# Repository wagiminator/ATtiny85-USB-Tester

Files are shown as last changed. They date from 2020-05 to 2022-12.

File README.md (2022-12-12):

# USB Power Tester
Simple USB Power Tester based on ATtiny25/45/85 and INA219. The device measures voltage, current, power, energy, capacity and displays the values on an OLED screen. You can switch between different screens by pressing the SET button.

- Project Video (YouTube): https://youtu.be/QKx8Vn_IfjU
- Design Files (EasyEDA): https://easyeda.com/wagiminator/attiny85-usb-tester

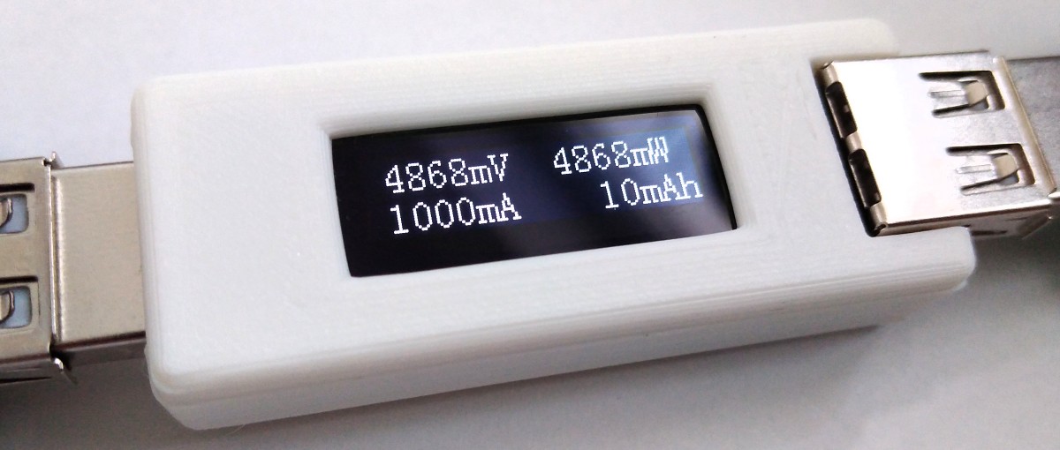
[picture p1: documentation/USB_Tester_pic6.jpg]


# Hardware
## USB Connectors
The device is equipped with a USB-A plug for the input and a USB-A socket for the output, so that it can be plugged between the power supply and the consumer. D+ and D- are passed through so that the consumer can negotiate the charging protocol.

## Voltage and Current Measurement
An [INA219](https://www.ti.com/lit/ds/symlink/ina219.pdf) is used to measure voltage and current. The INA219 is a current shunt and power monitor with an I²C-compatible interface. The device monitors both shunt voltage drop and bus supply voltage, with programmable conversion times and filtering. A programmable calibration value, combined with an internal multiplier, enables direct readouts of current in amperes. The selected shunt resistance of 8mΩ enables both a very small influence on the circuit and a measurement with a resolution of 1mA. For an accurate measurement, a shunt resistor with a low tolerance (1% or better) should be selected.

## User Interface
The user interface utilizes two buttons and an [SSD1306 128x32 pixels OLED display](http://aliexpress.com/wholesale?SearchText=128+32+0.91+oled). An [ATtiny24/45/85](https://ww1.microchip.com/downloads/en/DeviceDoc/Atmel-2586-AVR-8-bit-Microcontroller-ATtiny25-ATtiny45-ATtiny85_Datasheet.pdf) microcontroller handles the user interface as well as the calculation and  display of the values.

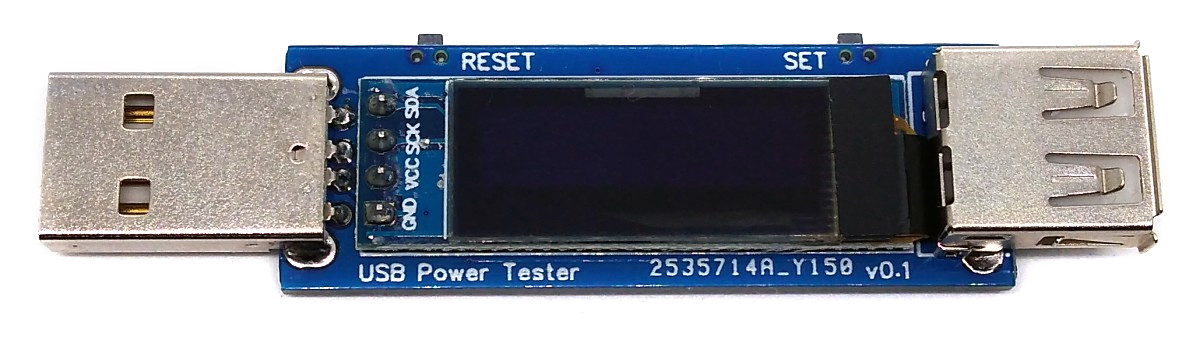
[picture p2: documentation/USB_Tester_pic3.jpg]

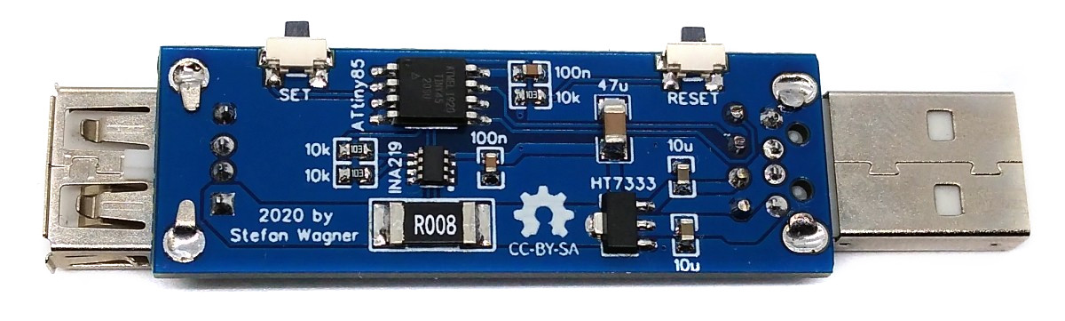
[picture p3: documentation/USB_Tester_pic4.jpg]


# Software
## Basic Principle
The INA219 continuously measures current and voltage and transmits the values to the ATtiny via I²C. From this, the ATtiny calculates the other values and displays them on the OLED screen.

## I²C OLED Implementation
The I²C protocol implementation is based on a crude bitbanging method. It was specifically designed for the limited resources of ATtiny10 and ATtiny13, but it works with some other AVRs (including the ATtiny25/45/85) as well. The functions for the OLED are adapted to the SSD1306 OLED module, but they can easily be modified to be used for other modules. In order to save resources, only the basic functionalities which are needed for this application are implemented. For a detailed information on the working principle of the I²C OLED implementation visit [TinyOLEDdemo](https://github.com/wagiminator/attiny13-tinyoleddemo).

## Accuracy of Time and Capacity Determination
The internal oscillator of the ATtiny is used to determine energy and capacity. The accuracy of the internal oscillator is +/-10% with the factory calibration. This can be improved to +/-2% or better by [manual calibration](https://github.com/wagiminator/ATtiny84-TinyCalibrator). The calibration value determined in this way can be set in the source code.

## Compiling and Uploading
Since there is no ICSP header on the board, you have to program the ATtiny either before soldering using an [SOP adapter](https://aliexpress.com/wholesale?SearchText=sop-8+150mil+adapter), or after soldering using an [EEPROM clip](https://aliexpress.com/wholesale?SearchText=sop8+eeprom+programming+clip). The [AVR Programmer Adapter](https://github.com/wagiminator/AVR-Programmer/tree/master/AVR_Programmer_Adapter) can help with this.

### If using the Arduino IDE
- Make sure you have installed [ATtinyCore](https://github.com/SpenceKonde/ATTinyCore).
- Go to **Tools -> Board -> ATtinyCore** and select **ATtiny25/45/85 (No bootloader)**.
- Go to **Tools** and choose the following board options:
  - **Chip:**           ATtiny25 or 45 or 85 (depending on your chip)
  - **Clock:**          1 MHz (internal)
  - **B.O.D.Level:**    B.O.D. enabled (2.7V)
  - Leave the rest at the default settings
- Connect your programmer to your PC and to the ATtiny.
- Go to **Tools -> Programmer** and select your ISP programmer (e.g. [USBasp](https://aliexpress.com/wholesale?SearchText=usbasp)).
- Go to **Tools -> Burn Bootloader** to burn the fuses.
- Open USB_Tester sketch and click **Upload**.

### If using the precompiled hex-file
- Make sure you have installed [avrdude](https://learn.adafruit.com/usbtinyisp/avrdude).
- Connect your programmer to your PC and to the ATtiny.
- Open a terminal.
- Navigate to the folder with the hex-file.
- Execute the following command (if necessary replace "usbasp" with the programmer you use):
  ```
  avrdude -c usbasp -p t85 -U lfuse:w:0x62:m -U hfuse:w:0xd5:m -U efuse:w:0xff:m -U flash:w:usb_tester.hex
  ```

### If using the makefile (Linux/Mac)
- Make sure you have installed [avr-gcc toolchain and avrdude](http://maxembedded.com/2015/06/setting-up-avr-gcc-toolchain-on-linux-and-mac-os-x/).
- Connect your programmer to your PC and to the ATtiny.
- Open a terminal.
- Navigate to the folder with the makefile and the Arduino sketch.
- Run `DEVICE=attiny85 PROGRMR=usbasp make install` to compile, burn the fuses and upload the firmware (change DEVICE and PROGRMR accordingly).

# Operating Instructions
1. Connect the device between a power supply and a consumer.
2. Use the SET button to switch between the different screens.
3. Use the RESET button to reset all values.

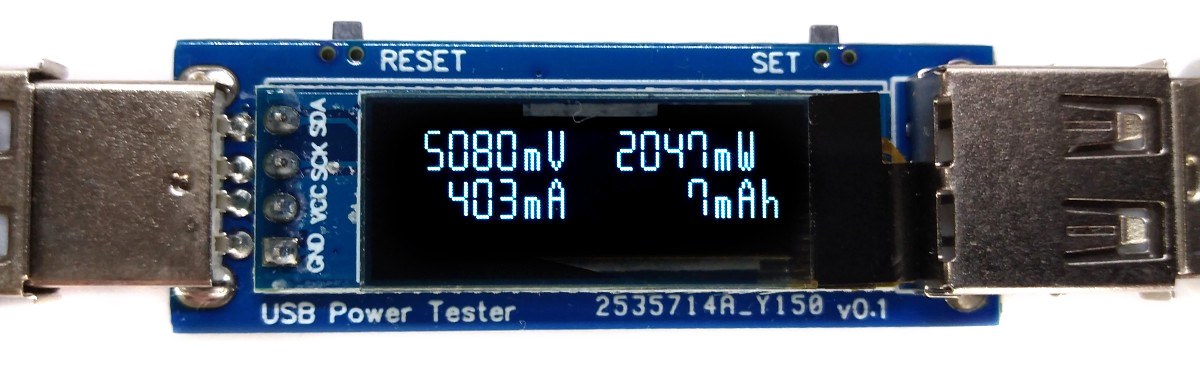
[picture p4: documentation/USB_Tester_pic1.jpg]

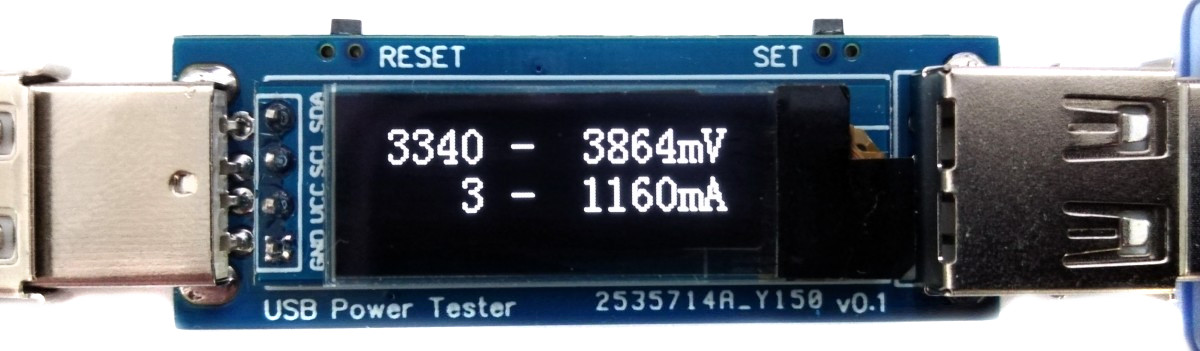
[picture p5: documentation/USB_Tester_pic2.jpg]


# Characteristics
|Parameter|Value|
|-|-|
|Voltage|3V - 12V|
|Current|max 5A|
|Voltage Measurement Resolution|4mV|
|Current Measurement Resolution|1mA|

# References, Links and Notes
1. [UBS Type-C Version](https://github.com/wagiminator/ATtiny85-USB-C-Tester)
2. [ATtiny25/45/85 Datasheet](https://ww1.microchip.com/downloads/en/DeviceDoc/Atmel-2586-AVR-8-bit-Microcontroller-ATtiny25-ATtiny45-ATtiny85_Datasheet.pdf)
3. [INA219 Datasheet](https://www.ti.com/lit/ds/symlink/ina219.pdf)
4. [SSD1306 Datasheet](https://cdn-shop.adafruit.com/datasheets/SSD1306.pdf)
5. [128x32 OLED on Aliexpress](http://aliexpress.com/wholesale?SearchText=128+32+0.91+oled)

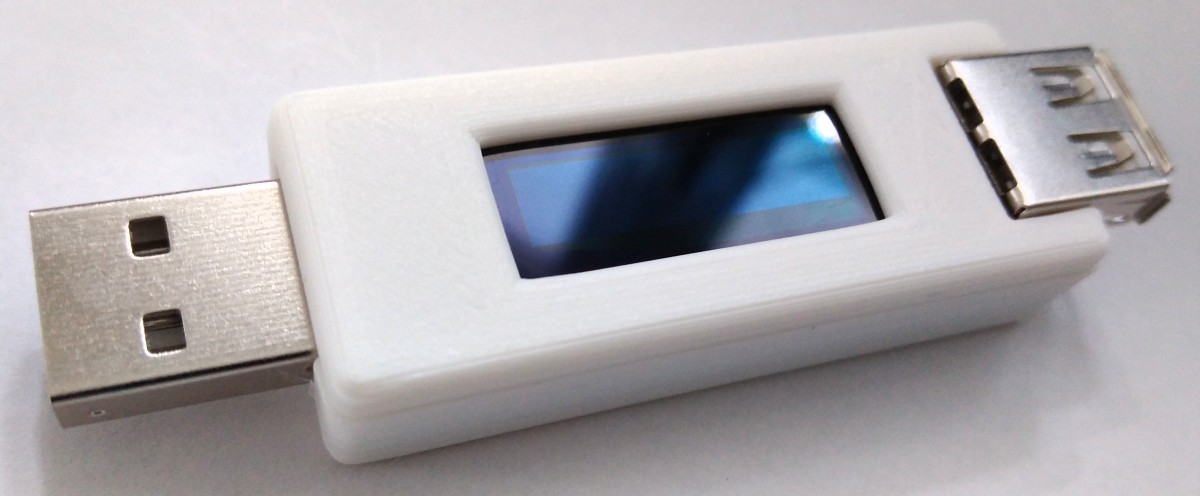
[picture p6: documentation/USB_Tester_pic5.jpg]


# License


This work is licensed under Creative Commons Attribution-ShareAlike 3.0 Unported License. 
(http://creativecommons.org/licenses/by-sa/3.0/)

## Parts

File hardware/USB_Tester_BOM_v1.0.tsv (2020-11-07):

ID | Name | Designator | Footprint | Quantity | Manufacturer Part | Manufacturer | Supplier | Supplier Part | LCSC Assembly
1 | OLED 0.91 | OLED | I2C OLED 0.91 | 1 | SSD1306 I2C OLED
2 | POWER OUT | USB2 | USB-2.0-A-F-90-JCJ-H9.36 | 1 | USB-A-F-90 | LCSC | LCSC | C168708
3 | POWER IN | USB1 | USB-M-48 | 1 | USB-05 | SOFNG | LCSC | C112454
4 | TS24CA | RESET,SET | SW-SMD_TS24CA | 2 | TS24CA | SHOU HAN | LCSC | C393942
5 | 10k | R3,R4,R1 | 0603 | 3 | 0603WAF1002T5E | UniOhm | LCSC | C25804
6 | ATtiny85 | U1 | SOIC-8_208MIL | 1 | ATTINY85-20SU | MICROCHIP | LCSC | C89852
7 | HT7333-A | U3 | SOT-89-3_L4.5-W2.5-P1.50-LS4.2-BR | 1 | HT7333-A | HOLTEK | LCSC | C21583 | Yes
8 | INA219 | U2 | SOT-23-8_L3.0-W1.7-P0.65-LS2.8-BL | 1 | INA219AIDCNR | TI | LCSC | C87469 | Yes
9 | 100n | C3,C1 | 0603 | 2 | CC0603KRX7R9BB104 | YAGEO | LCSC | C14663
10 | 10u | C4,C5 | 0603 | 2 | CL10A106MA8NRNC | SAMSUNG | LCSC | C96446
11 | 47u | C2 | 1206 | 1 | CL31A476MQHNNNE | SAMSUNG | LCSC | C68361
12 | R008 | R2 | 2512 | 1 | LCSR2512FR008Q9L | Resistor.Today | LCSC | C520396

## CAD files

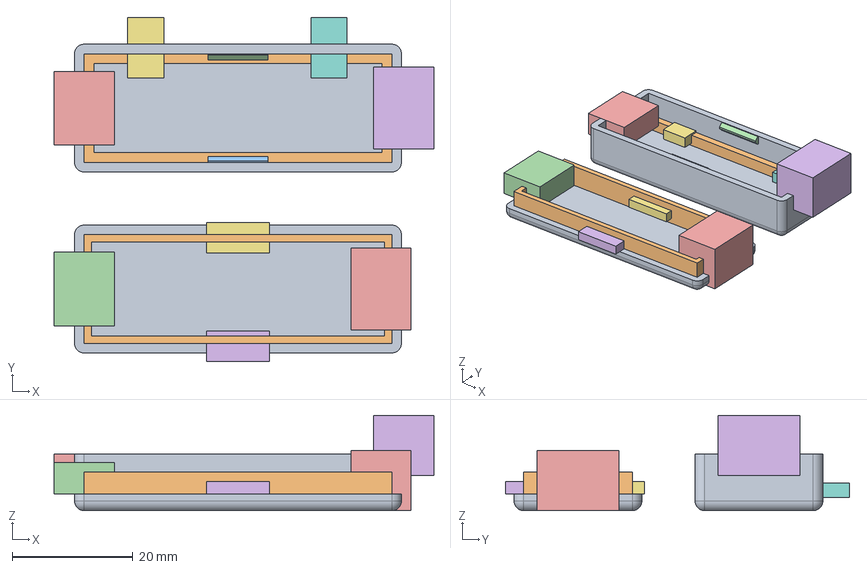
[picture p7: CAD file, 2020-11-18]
3dprint/USB_Tester_case_raw.fcstd
63.0 x 57.0 x 15.8 mm
Schale_unten
Auflage
Haken1
Haken2
USB_Stecker
USB_Buchse
Button1
Button2
Schale_oben
Rahmen
OLED
USB_Stecker2
USB_Buchse2
Oese1
Oese2

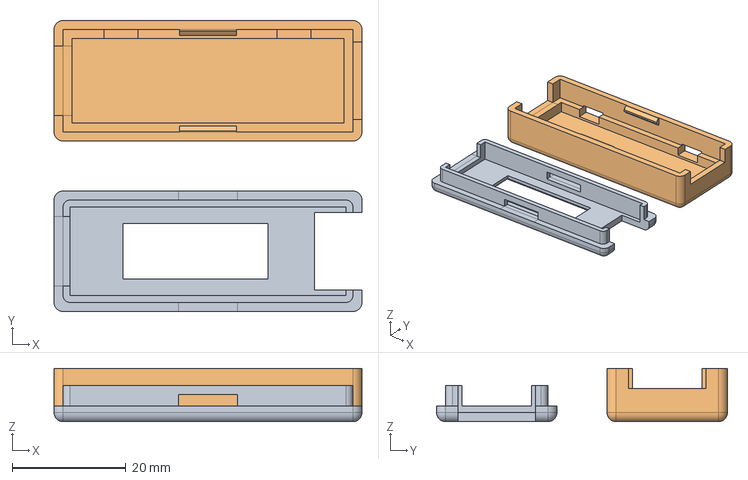
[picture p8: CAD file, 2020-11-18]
3dprint/USB_Tester_case.fcstd
54.2 x 51.2 x 9.40 mm
case_top
case_bottom

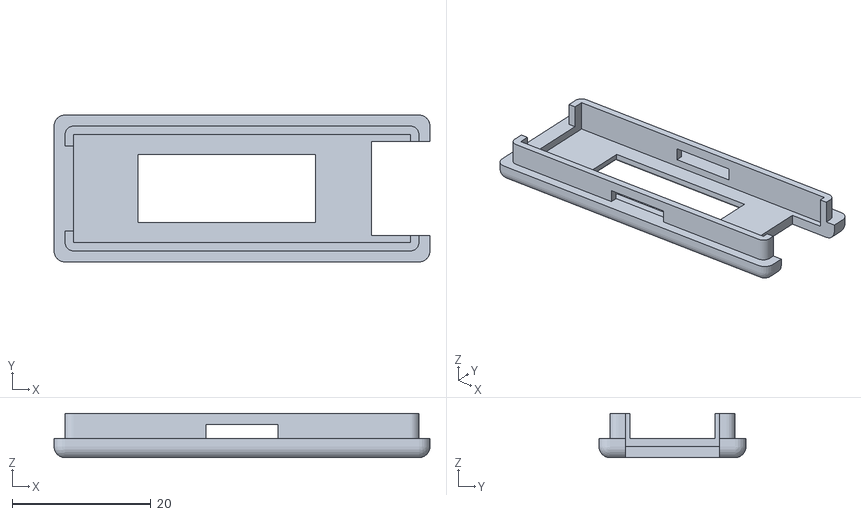
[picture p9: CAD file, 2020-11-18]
3dprint/USB_Tester_case_top.stl
54.2 x 21.2 x 6.40

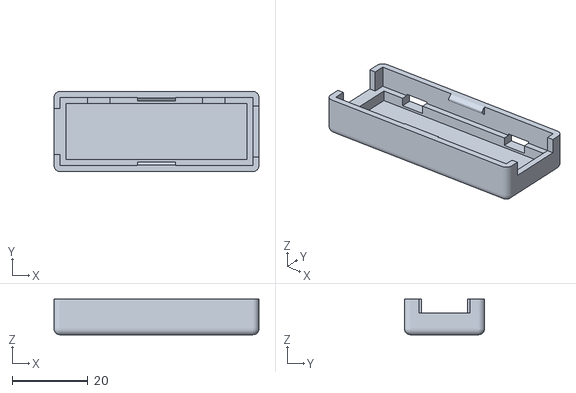
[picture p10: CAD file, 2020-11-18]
3dprint/USB_Tester_case_bottom.stl
54.2 x 21.2 x 9.40

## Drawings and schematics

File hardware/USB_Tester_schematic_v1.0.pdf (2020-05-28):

## ATtiny85 Microcontroller

# GNDVOUT VIN

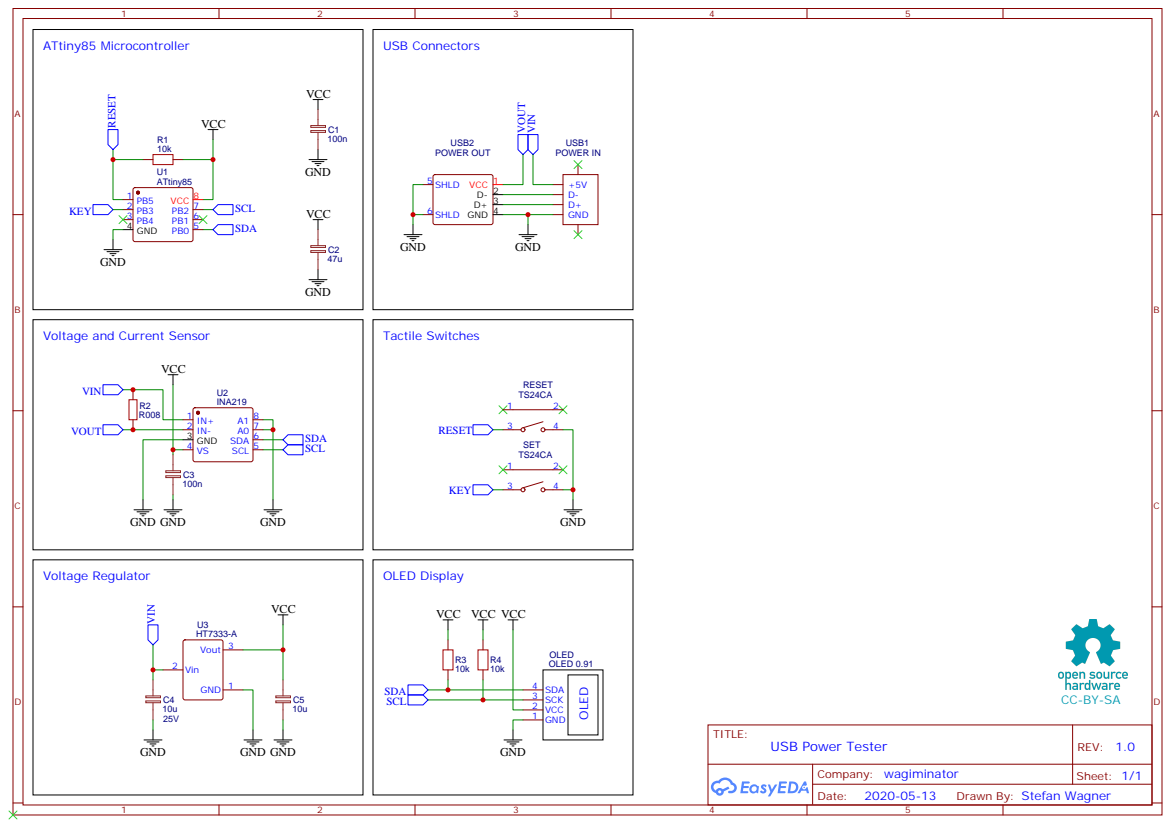
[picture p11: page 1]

Drawn By: Stefan Wagner

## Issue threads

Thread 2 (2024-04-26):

Using Arduino UNO to burn boot loader

Martius108, 2024-04-26:
Hello,

I burned the boot loader with the recommended settings and the help of an Arduino Uno as ISP without any issues.
Then I connected the ATtiny85 to my FTDI programmer and wanted to upload the sketch (still with the same settings). But I get an "Failure while uploading the sketch" error without any additional information in the log window. What can be the reason for this?

Thank's.

wagiminator, 2024-04-26:
Hi, burning the bootloader is only setting the fuses. There is actually no bootloader, so your FTDI adpater won't work. You have to upload the sketch with your Arduino as ISP (or any other ISP programmer) as well.

Martius108, 2024-04-26:
Great, thanks for your quick response!
Btw. how does it work with the oscillator calibration? I know a similar process from Snapduino - there it did work with the serial monitor ..

wagiminator, 2024-04-27:
You need a calibrator to determine the calibration value, e.g.: https://github.com/wagiminator/ATtiny84-TinyICOC

Martius108, 2024-04-28:
Thank you. The voltage value of my USB tester is around 0.1 V lower than it should be and the current is around 0.03 A higher than it should be. Is this a matter of calibration?
Is there an easier way to calibrate the oscillator? I used the Snapduino core to calibrate the bootloader/oscillator with the help of the serial monitor. Unfortunately Snapduino is very simple compared to your core and only works with 8 Mhz.

wagiminator, 2024-04-28:
Hi, the calibration of the oscillator does not affect the accuracy of the measurement of voltage and current. It influences time measurement and therefore, for example, energy calculation (mWh). The accuracy of the current and voltage measurement depends primarily on the quality of the shunt resistor. Here too, calibration can be done in software, but elsewhere. But first make sure that your comparison measurement was carried out correctly at the right measuring points using a calibrated measuring device. Most of the time this is where the fault lies (unless you have a really bad shunt).

On the subject of calibrating the oscillator: I have only used the method mentioned so far. This is also very easy if you have the device.

Martius108, 2024-04-28:
Thank you very much.

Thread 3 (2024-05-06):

INA219 not working/recognized

Martius108, 2024-05-06:
Hello,

I built up everything on a breadboard and run all components on 3.3 V. The display shows the initial values as long as only the ATtiny85 is attached to it. As soon as I connect the INA the display shows nothing. I have the pins A0 and A1 connected to ground so I had a look into your sketch and found out that you set the I2C address to 0x80, but in my case it should be 0x40. But that wasn’t the solution unfortunately. Any idea what else could be the issue here?

wagiminator, 2024-05-06:
The firmware uses the address with the write bit, so 0x80 = (0x40 << 1) | 0 is correct. You must have made something wrong in the wiring, maybe on the I2C bus because the OLED stopped to work.

Martius108, 2024-05-07:
Thank you. The wiring was ok, but under the magnifying glass I found a little shortcut at the INA chip. It’s not so easy to hand solder a SOT-23 :)

wagiminator, 2024-05-18:
You're right, I also have my difficulties with that!

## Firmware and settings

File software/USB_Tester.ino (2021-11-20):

// ===================================================================================
// Project:   USB Power Tester based on ATtiny25/45/85
// Version:   v1.4
// Year:      2020 - 2021
// Author:    Stefan Wagner
// Github:    https://github.com/wagiminator
// EasyEDA:   https://easyeda.com/wagiminator
// License:   http://creativecommons.org/licenses/by-sa/3.0/
// ===================================================================================
//
// Description:
// ------------
// Simple USB Power Tester based on ATtiny25/45/85 and INA219. The device
// measures voltage, current, power, energy, capacity and displays the values
// on an OLED screen. You can switch between different screens by pressing the
// SET button.
//
// References:
// -----------
// The I²C OLED implementation is based on TinyOLEDdemo
// https://github.com/wagiminator/ATtiny13-TinyOLEDdemo
//
// Wiring:
// -------
//                          +-\/-+
// RESET --- RST ADC0 PB5  1|°   |8  Vcc
//   SET ------- ADC3 PB3  2|    |7  PB2 ADC1 -------- OLED/INA SCK
//       ------- ADC2 PB4  3|    |6  PB1 AIN1 OC0B --- 
//                    GND  4|    |5  PB0 AIN0 OC0A --- OLED/INA SDA
//                          +----+
//
// Compilation Settings:
// ---------------------
// Core:    ATtinyCore (https://github.com/SpenceKonde/ATTinyCore)
// Board:   ATtiny25/45/85 (No bootloader)
// Chip:    ATtiny25 or 45 or 85 (depending on your chip)
// Clock:   1 MHz (internal)
// B.O.D.:  2.7V
//
// Leave the rest on default settings. Don't forget to "Burn bootloader"!
// No Arduino core functions or libraries are used. Use the makefile if 
// you want to compile without Arduino IDE.
//
// Note: The internal oscillator may need to be calibrated for precise
//       energy and capacity calculation.
//
// Fuse settings: -U lfuse:w:0x62:m -U hfuse:w:0xd5:m -U efuse:w:0xff:m 
//
// Operating Instructions:
// -----------------------
// Connect the device between a power supply and a consumer.
// Use the SET button to switch between the different screens.
// Use the RESET button to reset all values.


// ===================================================================================
// Libraries and Definitions
// ===================================================================================

// Oscillator calibration value (uncomment and set if necessary)
// #define OSCCAL_VAL  0x48

// Libraries
#include <avr/io.h>             // for GPIO
#include <avr/pgmspace.h>       // for data stored in program memory
#include <avr/interrupt.h>      // for interrupts
#include <util/delay.h>         // for delays

// Pin definitions
#define PIN_SDA     PB0         // I2C serial data pin
#define PIN_SCL     PB2         // I2C serial clock pin
#define PIN_SET     PB3         // SET button

// ===================================================================================
// I2C Master Implementation
// ===================================================================================

// I2C macros
#define I2C_SDA_HIGH()  DDRB &= ~(1<<PIN_SDA)   // release SDA   -> pulled HIGH by resistor
#define I2C_SDA_LOW()   DDRB |=  (1<<PIN_SDA)   // SDA as output -> pulled LOW  by MCU
#define I2C_SCL_HIGH()  DDRB &= ~(1<<PIN_SCL)   // release SCL   -> pulled HIGH by resistor
#define I2C_SCL_LOW()   DDRB |=  (1<<PIN_SCL)   // SCL as output -> pulled LOW  by MCU
#define I2C_SDA_READ()  (PINB &  (1<<PIN_SDA))  // read SDA line
#define I2C_CLOCKOUT()  I2C_SCL_HIGH();I2C_SCL_LOW()  // clock out

// I2C transmit one data byte to the slave, ignore ACK bit, no clock stretching allowed
void I2C_write(uint8_t data) {
  for(uint8_t i=8; i; i--, data<<=1) {          // transmit 8 bits, MSB first
    (data&0x80)?I2C_SDA_HIGH():I2C_SDA_LOW();   // SDA depending on bit
    I2C_CLOCKOUT();                             // clock out -> slave reads the bit
  }
  I2C_SDA_HIGH();                               // release SDA for ACK bit of slave
  I2C_CLOCKOUT();                               // 9th clock pulse is for the ignored ACK bit
}

// I2C start transmission
void I2C_start(uint8_t addr) {
  I2C_SDA_LOW();                                // start condition: SDA goes LOW first
  I2C_SCL_LOW();                                // start condition: SCL goes LOW second
  I2C_write(addr);                              // send slave address
}

// I2C restart transmission
void I2C_restart(uint8_t addr) {
  I2C_SDA_HIGH();                               // prepare SDA for HIGH to LOW transition
  I2C_SCL_HIGH();                               // restart condition: clock HIGH
  I2C_start(addr);                              // start again
}

// I2C stop transmission
void I2C_stop(void) {
  I2C_SDA_LOW();                                // prepare SDA for LOW to HIGH transition
  I2C_SCL_HIGH();                               // stop condition: SCL goes HIGH first
  I2C_SDA_HIGH();                               // stop condition: SDA goes HIGH second
}

// I2C receive one data byte from the slave (ack=0 for last byte, ack>0 if more bytes to follow)
uint8_t I2C_read(uint8_t ack) {
  uint8_t data = 0;                             // variable for the received byte
  I2C_SDA_HIGH();                               // release SDA -> will be toggled by slave
  for(uint8_t i=8; i; i--) {                    // receive 8 bits
    data <<= 1;                                 // bits shifted in right (MSB first)
    I2C_SCL_HIGH();                             // clock HIGH
    if(I2C_SDA_READ()) data |= 1;               // read bit
    I2C_SCL_LOW();                              // clock LOW -> slave prepares next bit
  }
  if(ack) I2C_SDA_LOW();                        // pull SDA LOW to acknowledge (ACK)
  I2C_CLOCKOUT();                               // clock out -> slave reads ACK bit
  return data;                                  // return the received byte
}

// ===================================================================================
// OLED Implementation
// ===================================================================================

// OLED definitions
#define OLED_ADDR       0x78    // OLED write address
#define OLED_CMD_MODE   0x00    // set command mode
#define OLED_DAT_MODE   0x40    // set data mode
#define OLED_INIT_LEN   11      // 9: no screen flip, 11: screen flip

// OLED init settings
const uint8_t OLED_INIT_CMD[] PROGMEM = {
  0xA8, 0x1F,                   // set multiplex for 128x32
  0x20, 0x01,                   // set vertical memory addressing mode
  0xDA, 0x02,                   // set COM pins hardware configuration to sequential
  0x8D, 0x14,                   // enable charge pump
  0xAF,                         // switch on OLED
  0xA1, 0xC8                    // flip the screen
};

// OLED 6x16 font
const uint8_t OLED_FONT[] PROGMEM = {
  0x7C, 0x1F, 0x02, 0x20, 0x02, 0x20, 0x02, 0x20, 0x02, 0x20, 0x7C, 0x1F, //  0 0
  0x00, 0x00, 0x00, 0x00, 0x00, 0x00, 0x00, 0x00, 0x00, 0x00, 0x7C, 0x1F, //  1 1
  0x00, 0x1F, 0x82, 0x20, 0x82, 0x20, 0x82, 0x20, 0x82, 0x20, 0x7C, 0x00, //  2 2
  0x00, 0x00, 0x82, 0x20, 0x82, 0x20, 0x82, 0x20, 0x82, 0x20, 0x7C, 0x1F, //  3 3
  0x7C, 0x00, 0x80, 0x00, 0x80, 0x00, 0x80, 0x00, 0x80, 0x00, 0x7C, 0x1F, //  4 4
  0x7C, 0x00, 0x82, 0x20, 0x82, 0x20, 0x82, 0x20, 0x82, 0x20, 0x00, 0x1F, //  5 5
  0x7C, 0x1F, 0x82, 0x20, 0x82, 0x20, 0x82, 0x20, 0x82, 0x20, 0x00, 0x1F, //  6 6
  0x7C, 0x00, 0x02, 0x00, 0x02, 0x00, 0x02, 0x00, 0x02, 0x00, 0x7C, 0x1F, //  7 7
  0x7C, 0x1F, 0x82, 0x20, 0x82, 0x20, 0x82, 0x20, 0x82, 0x20, 0x7C, 0x1F, //  8 8
  0x7C, 0x00, 0x82, 0x20, 0x82, 0x20, 0x82, 0x20, 0x82, 0x20, 0x7C, 0x1F, //  9 9
  0x00, 0x00, 0xF0, 0x3F, 0x8C, 0x00, 0x82, 0x00, 0x8C, 0x00, 0xF0, 0x3F, // 10 A
  0x00, 0x00, 0xFE, 0x07, 0x00, 0x18, 0x00, 0x20, 0x00, 0x18, 0xFE, 0x07, // 11 V
  0x00, 0x00, 0xFE, 0x1F, 0x00, 0x20, 0x00, 0x1F, 0x00, 0x20, 0xFE, 0x1F, // 12 W
  0x00, 0x00, 0xFE, 0x3F, 0x00, 0x01, 0x80, 0x00, 0x80, 0x00, 0x00, 0x3F, // 13 h
  0x00, 0x00, 0x80, 0x3F, 0x80, 0x00, 0x80, 0x3F, 0x80, 0x00, 0x00, 0x3F, // 14 m
  0x00, 0x00, 0x00, 0x00, 0x00, 0x30, 0x00, 0x30, 0x00, 0x00, 0x00, 0x00, // 15 .
  0x00, 0x00, 0x00, 0x00, 0x30, 0x06, 0x30, 0x06, 0x00, 0x00, 0x00, 0x00, // 16 :
  0x80, 0x00, 0x80, 0x00, 0x80, 0x00, 0x80, 0x00, 0x80, 0x00, 0x80, 0x00, // 17 -
  0x00, 0x00, 0x00, 0x00, 0x00, 0x00, 0x00, 0x00, 0x00, 0x00, 0x00, 0x00  // 18 SPACE
};

// Character definitions
#define DECIMAL 15
#define COLON   16
#define SPACE   18

// OLED BCD conversion array
const uint16_t DIVIDER[] PROGMEM = {10000, 1000, 100, 10, 1};

// OLED init function
void OLED_init(void) {
  I2C_start(OLED_ADDR);                         // start transmission to OLED
  I2C_write(OLED_CMD_MODE);                     // set command mode
  for(uint8_t i=0; i<OLED_INIT_LEN; i++) 
    I2C_write(pgm_read_byte(&OLED_INIT_CMD[i]));// send the command bytes
  I2C_stop();                                   // stop transmission
}

// OLED set the cursor
void OLED_setCursor(uint8_t xpos, uint8_t ypos) {
  I2C_start(OLED_ADDR);                         // start transmission to OLED
  I2C_write(OLED_CMD_MODE);                     // set command mode
  I2C_write(0x22);                              // command for min/max page
  I2C_write(ypos); I2C_write(ypos+1);           // min: ypos; max: ypos+1
  I2C_write(xpos & 0x0F);                       // set low nibble of start column
  I2C_write(0x10 | (xpos >> 4));                // set high nibble of start column
  I2C_write(0xB0 | (ypos));                     // set start page
  I2C_stop();                                   // stop transmission
}

// OLED clear screen
void OLED_clearScreen(void) {
  OLED_setCursor(0, 0);                         // set cursor at upper half
  I2C_start(OLED_ADDR);                         // start transmission to OLED
  I2C_write(OLED_DAT_MODE);                     // set data mode
  uint8_t i = 0;                                // count variable
  do {I2C_write(0x00);} while(--i);             // clear upper half
  I2C_stop();                                   // stop transmission
  OLED_setCursor(0, 2);                         // set cursor at lower half
  I2C_start(OLED_ADDR);                         // start transmission to OLED
  I2C_write(OLED_DAT_MODE);                     // set data mode
  do {I2C_write(0x00);} while(--i);             // clear upper half
  I2C_stop();                                   // stop transmission
}

// OLED plot a character
void OLED_plotChar(uint8_t ch) {
  ch = (ch << 3) + (ch << 2);                   // calculate position of character in font array
  I2C_write(0x00); I2C_write(0x00);             // print spacing between characters
  for(uint8_t i=12; i; i--) I2C_write(pgm_read_byte(&OLED_FONT[ch++])); // print character
  I2C_write(0x00); I2C_write(0x00);             // print spacing between characters
}

// OLED print a character
void OLED_printChar(uint8_t ch) {
  I2C_start(OLED_ADDR);                         // start transmission to OLED
  I2C_write(OLED_DAT_MODE);                     // set data mode
  OLED_plotChar(ch);                            // plot the character
  I2C_stop();                                   // stop transmission
}

// OLED print a string from program memory; terminator: 255
void OLED_printPrg(const uint8_t* p) {
  I2C_start(OLED_ADDR);                         // start transmission to OLED
  I2C_write(OLED_DAT_MODE);                     // set data mode
  uint8_t ch = pgm_read_byte(p);                // read first character from program memory
  while(ch < 255) {                             // repeat until string terminator
    OLED_plotChar(ch);                          // plot character on OLED
    ch = pgm_read_byte(++p);                    // read next character
  }
  I2C_stop();                                   // stop transmission
}

// OLED print 16-bit value as 5-digit decimal (BCD conversion by substraction method)
void OLED_printDec16(uint16_t value) {
  uint8_t leadflag = 0;                         // flag for leading spaces
  I2C_start(OLED_ADDR);                         // start transmission to OLED
  I2C_write(OLED_DAT_MODE);                     // set data mode
  for(uint8_t digit = 0; digit < 5; digit++) {  // 5 digits
    uint8_t digitval = 0;                       // start with digit value 0
    uint16_t divider = pgm_read_word(&DIVIDER[digit]); // current divider
    while(value >= divider) {                   // if current divider fits into the value
      leadflag = 1;                             // end of leading spaces
      digitval++;                               // increase digit value
      value -= divider;                         // decrease value by divider
    }
    if(leadflag || (digit == 4)) OLED_plotChar(digitval); // print the digit
    else OLED_plotChar(SPACE);                  // or print leading space
  }
  I2C_stop();                                   // stop transmission
}

// OLED print 16-bit value as 3-digit decimal (BCD conversion by substraction method)
void OLED_printDec12(uint16_t value) {
  I2C_start(OLED_ADDR);                         // start transmission to OLED
  I2C_write(OLED_DAT_MODE);                     // set data mode
  for(uint8_t digit = 2; digit < 5; digit++) {  // 3 digits
    uint8_t digitval = 0;                       // start with digit value 0
    uint16_t divider = pgm_read_word(&DIVIDER[digit]); // current divider
    while(value >= divider) {                   // if current divider fits into the value
      digitval++;                               // increase digit value
      value -= divider;                         // decrease value by divider
    }
    OLED_plotChar(digitval);                    // print the digit
  }
  I2C_stop();                                   // stop transmission
}

// OLED print 8-bit value as 2-digit decimal (BCD conversion by substraction method)
void OLED_printDec8(uint8_t value) {
  I2C_start(OLED_ADDR);                         // start transmission to OLED
  I2C_write(OLED_DAT_MODE);                     // set data mode
  uint8_t digitval = 0;                         // start with digit value 0
  while(value >= 10) {                          // if current divider fits into the value
    digitval++;                                 // increase digit value
    value -= 10;                                // decrease value by divider
  }
  OLED_plotChar(digitval);                      // print first digit
  OLED_plotChar(value);                         // print second digit
  I2C_stop();                                   // stop transmission
}

// ===================================================================================
// INA219 Implementation
// ===================================================================================

// INA219 register values
#define INA_ADDR        0x80                    // I2C write address of INA219
#define INA_CONFIG      0b0000011111111111      // INA config register according to datasheet
#define INA_CALIB       5120                    // INA calibration register according to R_SHUNT
#define INA_REG_CONFIG  0x00                    // INA configuration register address
#define INA_REG_CALIB   0x05                    // INA calibration register address
#define INA_REG_SHUNT   0x01                    // INA shunt voltage register address
#define INA_REG_VOLTAGE 0x02                    // INA bus voltage register address
#define INA_REG_POWER   0x03                    // INA power register address
#define INA_REG_CURRENT 0x04                    // INA current register address

// INA219 write a register value
void INA_write(uint8_t reg, uint16_t value) {
  I2C_start(INA_ADDR);                          // start transmission to INA219
  I2C_write(reg);                               // write register address
  I2C_write(value >> 8);                        // write register content high byte
  I2C_write(value);                             // write register content low  byte
  I2C_stop();                                   // stop transmission
}

// INA219 read a register
uint16_t INA_read(uint8_t reg) {
  uint16_t result;                              // result variable
  I2C_start(INA_ADDR);                          // start transmission to INA219
  I2C_write(reg);                               // write register address
  I2C_restart(INA_ADDR | 0x01);                 // restart for reading
  result = (uint16_t)(I2C_read(1) << 8) | I2C_read(0);  // read register content
  I2C_stop();                                   // stop transmission
  return result;                                // return result
}

// INA219 write inital configuration and calibration values
void INA_init(void) {
  INA_write(INA_REG_CONFIG, INA_CONFIG);        // write INA219 configuration
  INA_write(INA_REG_CALIB,  INA_CALIB);         // write INA219 calibration
}

// INA219 read voltage
uint16_t INA_readVoltage(void) {
  return((INA_read(INA_REG_VOLTAGE) >> 1) & 0xFFFC);
}
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
int main(void) {
  // Local variables
  uint16_t  voltage, current, power;            // voltage in mV, current in mA, power in mW
  uint16_t  minvoltage = 65535, maxvoltage = 0; // min/max voltages in mV
  uint16_t  mincurrent = 65535, maxcurrent = 0; // min/max current in mA
  uint16_t  minpower   = 65535, maxpower   = 0; // min/max power in mV
  uint32_t  lastmillis, nowmillis, interval;    // for timing calculation in millis
  uint32_t  duration = 0;                       // total duration in millis
  uint16_t  seconds;                            // total duration in seconds
  uint32_t  capacity = 0, energy = 0;           // counter for capacity in uAh and energy in uWh
  uint8_t   primescreen = 0;                    // screen selection flag
  uint8_t   lastbutton  = 1;                    // button flag (0: button pressed)

  // Set oscillator calibration value
  #ifdef OSCCAL_VAL
    OSCCAL = OSCCAL_VAL;                        // set the value if defined above
  #endif

  // Setup
  PORTB |= (1<<PIN_SET);                        // pullup for set button
  MIL_init();                                   // init millis counter
  INA_init();                                   // init INA219
  OLED_init();                                  // init OLED
  OLED_clearScreen();                           // clear screen
  lastmillis = MIL_read();                      // read millis counter

  // Loop
  while(1) {
    // Read sensor values
    voltage = INA_readVoltage();                // read voltage in mV from INA219
    current = INA_readCurrent();                // read current in mA from INA219  

    // Calculate timings
    nowmillis   = MIL_read();                   // read millis counter
    interval    = nowmillis - lastmillis;       // calculate recent time interval
    lastmillis  = nowmillis;                    // reset lastmillis
    duration   += interval;                     // calculate total duration in millis
    seconds     = duration / 1000;              // calculate total duration in seconds
  
    // Calculate power, capacity and energy
    power = (uint32_t)voltage * current / 1000; // calculate power    in mW
    capacity += interval * current / 3600;      // calculate capacity in uAh
    energy   += interval * power   / 3600;      // calculate energy   in uWh

    // Update min/max values
    if(minvoltage > voltage) minvoltage = voltage;
    if(maxvoltage < voltage) maxvoltage = voltage;
    if(mincurrent > current) mincurrent = current;
    if(maxcurrent < current) maxcurrent = current;
    if(minpower   > power  ) minpower   = power;
    if(maxpower   < power  ) maxpower   = power;

    // Check SET button and set screen flag accordingly
    if(PINB & (1<<PIN_SET)) lastbutton = 0;
    else if(!lastbutton) {
      if(++primescreen > 4) primescreen = 0;
      OLED_clearScreen();
      lastbutton  = 1;
    }

    // Display values on the OLED
    switch(primescreen) {
      case 0:   OLED_setCursor(0,0);
                OLED_printDec16(voltage); OLED_printPrg(mV);
                OLED_printDec16(power);   OLED_printPrg(mW);
                OLED_setCursor(0,2);
                OLED_printDec16(current); OLED_printPrg(mA);
                OLED_printDec16(capacity / 1000); OLED_printPrg(mAh);
                break;
      case 1:   OLED_setCursor(0,0);
                OLED_printDec16(minvoltage); OLED_printPrg(SEP);
                OLED_printDec16(maxvoltage); OLED_printPrg(mV);
                OLED_setCursor(0,2);
                OLED_printDec16(mincurrent); OLED_printPrg(SEP);
                OLED_printDec16(maxcurrent); OLED_printPrg(mA);
                break;
      case 2:   OLED_setCursor(0,1);
                OLED_printDec16(minpower);   OLED_printPrg(SEP);
                OLED_printDec16(maxpower);   OLED_printPrg(mW);
                break;
      case 3:   // ATtiny25 without decimal places to make it fit into the flash
                #if defined(__AVR_ATtiny25__)
                  OLED_setCursor(32,0);
                  OLED_printDec16(capacity / 1000); OLED_printPrg(mAh);
                  OLED_setCursor(32,2);
                  OLED_printDec16(energy / 1000);   OLED_printPrg(mWh);
                #else
                  OLED_setCursor(16,0);
                  OLED_printDec16(capacity / 1000); OLED_printChar(DECIMAL);
                  OLED_printDec12(capacity % 1000); OLED_printPrg(mAh);
                  OLED_setCursor(16,2);
                  OLED_printDec16(energy / 1000);   OLED_printChar(DECIMAL);
                  OLED_printDec12(energy % 1000);   OLED_printPrg(mWh);
                #endif
                break;
      case 4:   OLED_setCursor(32,1);
                OLED_printDec8(seconds / 3600); OLED_printChar(COLON);
                seconds %= 3600;
                OLED_printDec8(seconds / 60  ); OLED_printChar(COLON);            
                OLED_printDec8(seconds % 60  ); 
                break;
      default:  break;
    } 
    _delay_ms(50);
  }
}

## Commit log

2020-05-28 Uploading files
    [USB_Tester_BOM_v1.0.csv]
2020-11-07 Update files
    [USB_Tester_BOM_v1.0.csv]
2021-03-25 Easier hand soldering
